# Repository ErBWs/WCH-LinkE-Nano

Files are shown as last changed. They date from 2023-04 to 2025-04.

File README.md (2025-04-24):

# WCH-LinkE-Nano

 自制WCH-LinkE

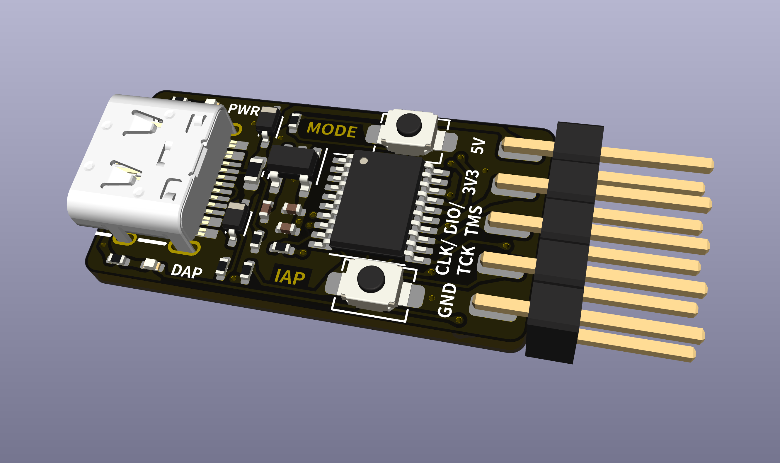
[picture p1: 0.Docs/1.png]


## 使用教程

1. 准备好一个WCH-Link，可以考虑我之前制作的[这款](https://oshwhub.com/erbw_s/wch-link)。

   > 这个下载器需要另一个wch-link才可以自制，很麻烦所以我一开始没考虑，但是下载速度的确很快

2. 直接打开`3.Software`文件夹内的`WCH-LinkUtility.exe`

3. 载入`2.Firmware`内的`.bin`文件并烧录

4. 断电重新上电即可作为正常WCH-LinkE使用

5. 持续按住MODE键上电，等待一段时间后松开可在`Link-RV`和`DAP`模式中切换

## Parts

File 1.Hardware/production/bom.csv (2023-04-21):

Designator | Footprint | Quantity | Value | LCSC Part #
C1, C8 | C_0402 | 2 | 100nF
C2 | C_0402 | 1 | 10uF
C3 | C_0402 | 1 | 10nF
C4, C5 | C_0402 | 2 | 22pF
D1 | LED_0402 | 1 | GREEN
D2 | SOD-323 | 1 | ESD
D3 | SOD-323 | 1 | 1N5819
D4 | LED_0402 | 1 | BLUE
F1 | 0603 | 1 | 500mA
J1 | USB-Type-C_SMD_16P | 1 | USB-Type-C
J2 | Debug_Header_2x05 | 1 | Conn_02x05_Odd_Even
R1, R2 | R_0402 | 2 | 4.7K
R3, R4, R6 | R_0402 | 3 | 10K
R5 | R_0402 | 1 | 1K
R7 | R_0402 | 1 | 0R
SW1 | BUTTON_3x4 | 1 | ModeS
SW2 | BUTTON_3x4 | 1 | IAP
U1 | SOT-23-5 | 1 | RT9013-33GB
U2 | TSSOP-20_4.4x6.5mm_P0.65mm | 1 | CH32V305FBT6
Y1 | Crystal_SMD_3225_4P | 1 | 12MHz

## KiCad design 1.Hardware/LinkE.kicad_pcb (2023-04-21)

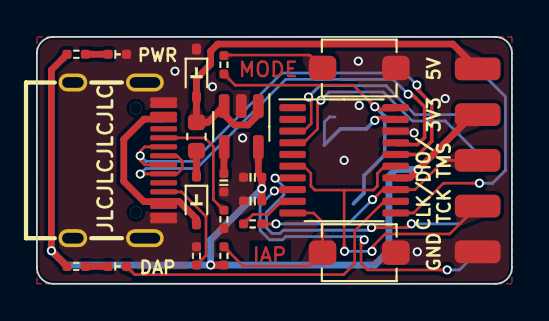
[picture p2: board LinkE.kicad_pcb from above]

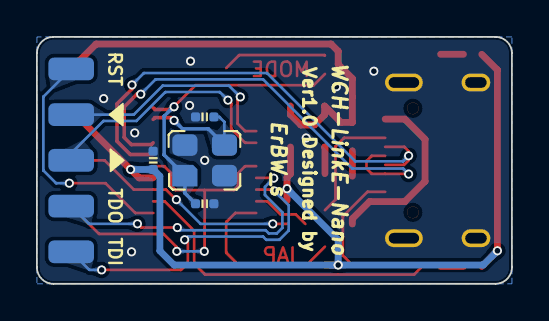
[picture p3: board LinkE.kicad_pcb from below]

Board: 2 copper layers, 26.4 x 13.7 mm, 25 parts (4 on the bottom side), 25 nets.

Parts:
C1, C8: 100nF; C_0402
C2: 10uF; C_0402
C3: 10nF; C_0402
C4, C5: 22pF; C_0402
D1: GREEN; LED_0402
D2: ESD; SOD-323
D3: 1N5819; SOD-323
D4: BLUE; LED_0402
F1: 500mA; Fuse_0603_1608Metric
J2: Conn_02x05_Odd_Even; Debug_Header_2x05
J?: USB-Type-C; USB-Type-C_SMD_16P
R1, R2: 4.7K; R_0402
R3, R4, R6: 10K; R_0402
R5: 1K; R_0402
R7: 0R; R_0402
SW1: ModeS; BUTTON_3x4
SW2: IAP; BUTTON_3x4
U1: RT9013-33GB; SOT-23-5
U2: CH32V305FBT6; TSSOP-20_4.4x6.5mm_P0.65mm
Y1: 12MHz; Crystal_SMD_3225_4P

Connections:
+3.3V: C1.1, C2.1, C8.1, J2.3, R3.1, R4.1, R6.1, U1.5 (VOUT), U2.14 (VDD33/VIO)
+5V: D3.2 (A), J?.A4 (VBUS), J?.A9 (VBUS), J?.B4 (VBUS), J?.B9 (VBUS)
+5VA: D2.2 (A2), F1.2, J2.1, U1.1 (VIN), U1.3 (EN)
/IAP: R6.2, SW2.1, U2.10 (PC7)
/LED_CON: D4.2 (A), U2.12 (PC9/PA8/UART1_RX)
/OSC_N: C4.1, R7.1, U2.20 (OSC_OUT/PD1), Y1.1
/OSC_P: C5.1, U2.19 (OSC_IN/PD0), Y1.3
/RST: J2.2, U2.11 (PC8)
/RX: J2.6, U2.4 (PB11/UART3_RX/I2C2_SDA)
/SWCLK: J2.7, U2.6 (PB13/SPI2_SCK/UART3_CTS/CAN2_TX), U2.15 (PA14/SWCLK)
/SWDIO: J2.5, R5.1, U2.13 (PA9/UART1_RTS/PA13/SWDIO)
/TDI: J2.10, U2.8 (PB15/SPI2_MOSI/UART1_TX)
/TDO: J2.8, U2.7 (PB14/SPI2_MISO/UART3_RTS)
/TX: J2.4, U2.3 (PB10/UART3_TX/I2C2_SCL)
/USB_N: J?.A7 (D-), J?.B7 (D-), U2.16 (PB6/USB2DM/UART1X_TX)
/USB_P: J?.A6 (D+), J?.B6 (D+), U2.17 (PB7/USB2DP/UART1X_RX)
GND: C1.2, C2.2, C3.2, C4.2, C5.2, C8.2, D1.2 (A), D2.1 (A1), J2.9, J?.A1 (GND), J?.A12 (GND), J?.B1 (GND), J?.B12 (GND), J?.S1 (SH), R1.2, R2.2, SW1.2, SW2.2, U1.2 (GND), U2.18 (VSS/GND), Y1.2, Y1.4
unnamed: D1.1 (K), R3.2
unnamed: D3.1 (K), F1.1
unnamed: D4.1 (K), R4.2
unnamed: J?.A5 (CC1), R1.1
unnamed: J?.B5 (CC2), R2.1
unnamed: R7.2, SW1.1
unnamed: C3.1, U1.4 (NC)
unnamed: R5.2, U2.9 (PC6)

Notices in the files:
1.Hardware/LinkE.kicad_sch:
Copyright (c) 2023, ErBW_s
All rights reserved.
